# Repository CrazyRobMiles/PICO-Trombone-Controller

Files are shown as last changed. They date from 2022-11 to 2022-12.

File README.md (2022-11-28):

# PICO Trombone controller

Designs and software for a trombone controller.

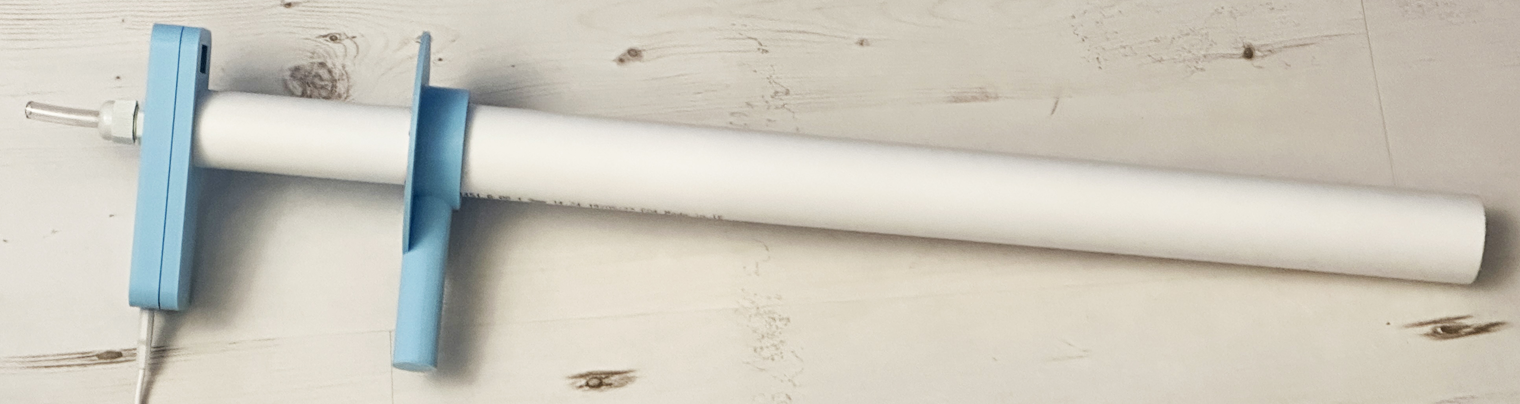
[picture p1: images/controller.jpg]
Trombone controller


## Controlling a mouse with trombone action

The controller can be used to play the game Trombone Champ: https://www.trombonechamp.com/

It replaces the mouse controller. There is a breath controlled version which uses a BMP280 pressure sensor and a button controlled version. 

You will need:

* A Raspberry Pi PICO
* A VL53L4CD time of flight sensor
* A BMP280 temperature and pressure sensor or two pushbuttons that will fit in 12mm diameter holes
* 45 cm of 32mm diameter waste pipe
* 45 cm of 40mm diameter waste pipe
* A micro-USB cable to link the PICO to the host
* Connecting wire. The author used coloured wire wrap (search for "30 AWG wire wrap") which needed a wire wrap tool (search for "wire wrap tool")..
* A case and target. There is a 3D printable set one which fits around the tubing and works well.
* PG9 cable gland for the mouthpiece connector if you are using the BMP280
* 8mm clear vinyl tubing for the mouthpiece. You’ll need a length of around 50mm for each mouthpiece. 
* Screws. You'll need some screws size M2 4mm in length to fix the environmental sensor and PICO to the case (search for "laptop screws").

## Circuit Diagram

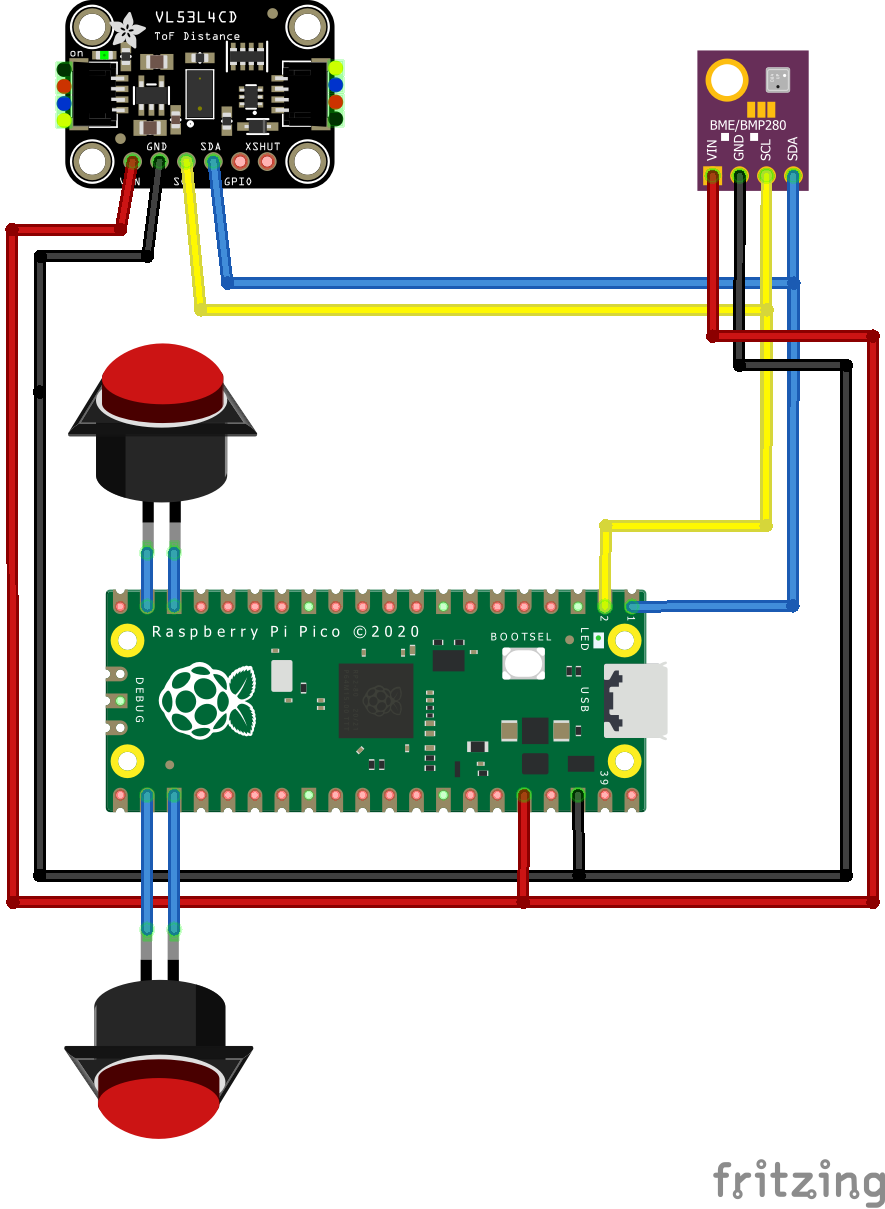
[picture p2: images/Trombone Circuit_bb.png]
Circuit Diagram


The diagram shows the connection for both buttons and air pressur sensor. Ignore the one you're not using. 

## Software Installation

Install Circuit Python 7.0 on your PICO and then copy the lib folder and the code.py file to the PICO. When you power on the PICO it will then run the code. You may need to edit the code.py file to select the input method you are using. 

## Case

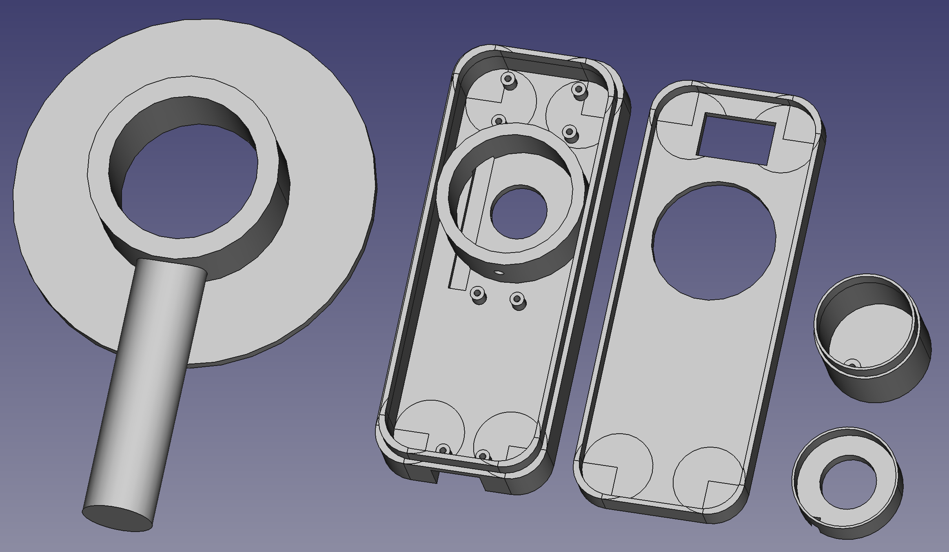
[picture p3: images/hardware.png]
Case Components


The components for the case can be found in the case folder. 

Enjoy playing your trombone
Rob Miles

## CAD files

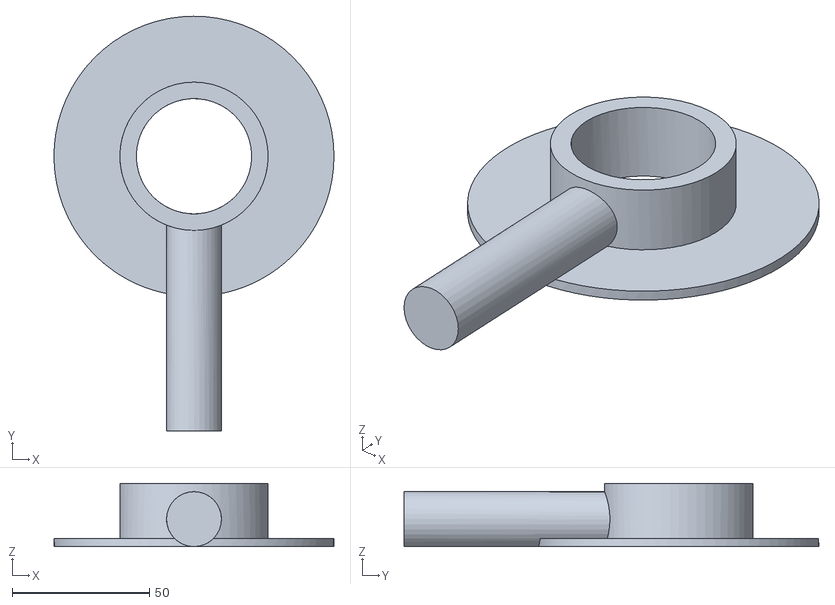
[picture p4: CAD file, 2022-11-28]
case/target.stl
102.0 x 151.0 x 23.0

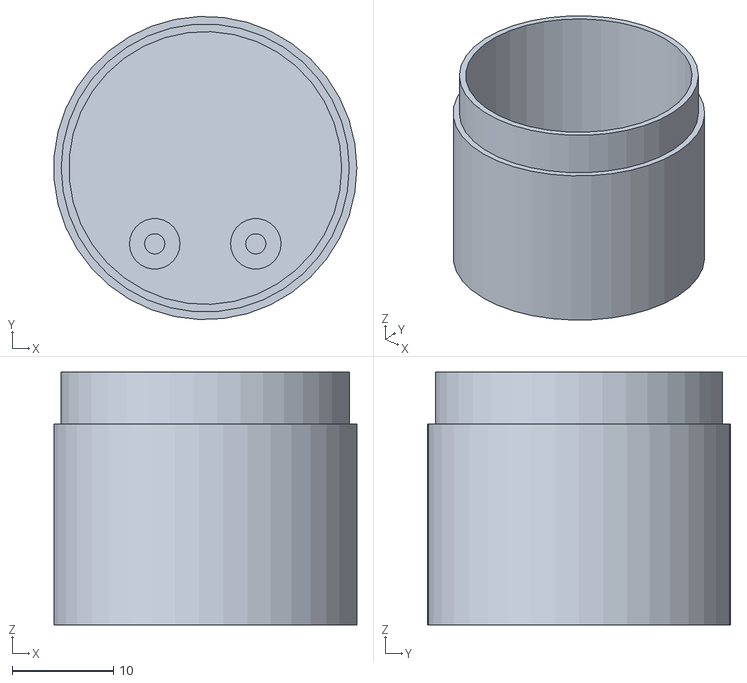
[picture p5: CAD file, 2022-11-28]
case/Pressure Sensor Holder Base.stl
30.0 x 30.0 x 25.0

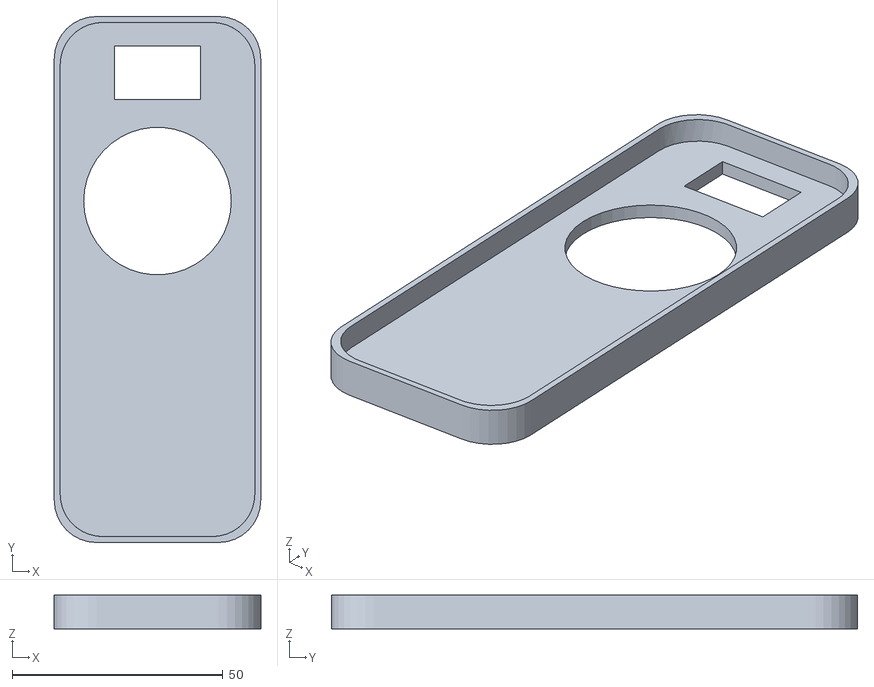
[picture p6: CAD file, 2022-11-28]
case/Top.stl
49.0 x 124.8 x 8.00

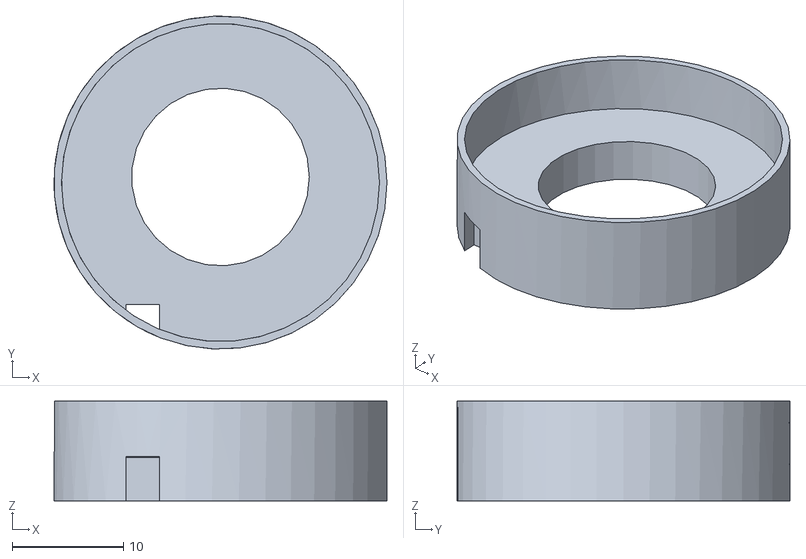
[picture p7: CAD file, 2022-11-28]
case/Pressure Sensor Holder Top.stl
30.0 x 30.0 x 9.00

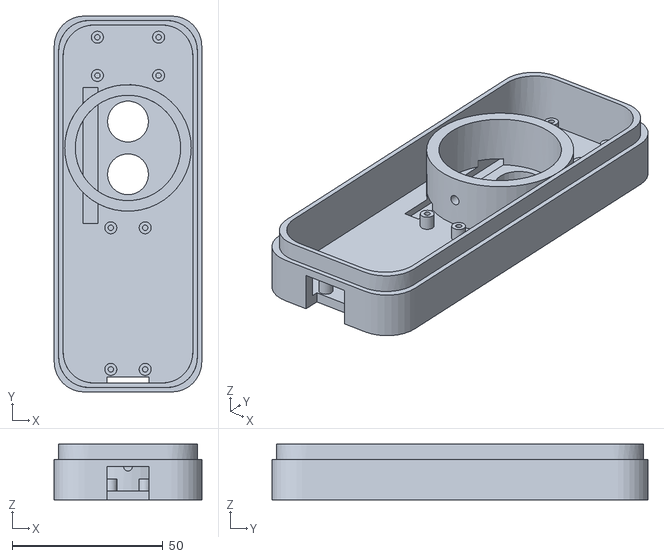
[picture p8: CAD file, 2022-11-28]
case/Two Buttons Base.stl
49.0 x 124.8 x 18.5

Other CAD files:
case/Pressure Sensor Base.stl

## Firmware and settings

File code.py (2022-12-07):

# Trombone controller
#

import board
import busio
import adafruit_vl53l4cd
import adafruit_vl53l0x
import time
import usb_hid
from digitalio import DigitalInOut, Direction, Pull

import adafruit_bmp280
from adafruit_hid.mouse import Mouse

mouse = Mouse(usb_hid.devices)


class Distance():

    def __init__(self):
        self.valuePos = 0
        self.valueTotal = 0
        self.rollingAverageLength = 5
        self.rollingValues = []

        print("Rolling average length:{}".format(self.rollingAverageLength))

        for i in range(0, self.rollingAverageLength):
            self.rollingValues.append(0)

    def distance_moved(self):
        new_pos = self.blockingWaitForValue()
        diff = new_pos - self.current_pos
        self.current_pos = new_pos
        return diff

    def start(self):
        pass

    def blockingWaitForAverage(self, timeout=1):
        distance = self.blockingWaitForValue(timeout=1)

        self.valueTotal = self.valueTotal + distance
        self.valueTotal = self.valueTotal - self.rollingValues[self.valuePos]
        self.rollingValues[self.valuePos] = distance
        self.valuePos = self.valuePos + 1
        if self.valuePos == self.rollingAverageLength:
            self.valuePos = 0
        return int(self.valueTotal/self.rollingAverageLength*10)

    def speed_test(self):
        readingCount = 0
        ot = time.time()
        while True:
            x = self.blockingWaitForValue()
            readingCount = readingCount + 1
            nt = time.time()
            if nt != ot:
                print(readingCount, x)
                readingCount = 0
                ot = nt

    def dump(self):
        while True:
            print(self.blockingWaitForValue())


class DistanceSensor_vl53l0x(Distance):
# https://docs.circuitpython.org/projects/vl53l0x/en/latest/
    def __init__(self, i2c):
        super(DistanceSensor_vl53l0x, self).__init__()
        self.vl53 = adafruit_vl53l0x.VL53L0X(i2c)
        self.vl53.inter_measurement = 10
        print("VL53L0X Starting")

    def start(self):
        super(DistanceSensor_vl53l0x, self).start()
        self.vl53.timing_budget = 10
        self.vl53.start_continuous()
        self.current_pos = self.blockingWaitForValue()

    def blockingWaitForValue(self, timeout=1):
        end = time.monotonic() + 1
        while not self.vl53.data_ready:
            if time.monotonic() > end:
                break
        if time.monotonic() > end:
            return -1
        else:
            return self.vl53.range


class DistanceSensor_vl53l4cd(Distance):
# https://docs.circuitpython.org/projects/vl53l4cd/en/latest/api.html#adafruit_vl53l4cd.VL53L4CD
    def __init__(self, i2c):
        super(DistanceSensor_vl53l4cd, self).__init__()
        self.vl53 = adafruit_vl53l4cd.VL53L4CD(i2c)
        print("VL53L4CD Starting")

    def start(self):
        super(DistanceSensor_vl53l4cd, self).start()
        self.vl53.timing_budget = 10
        self.vl53.start_ranging()
        self.current_pos = self.blockingWaitForValue()

    def blockingWaitForValue(self, timeout=1):
        end = time.monotonic() + 1
        while not self.vl53.data_ready:
            if time.monotonic() > end:
                break
        if time.monotonic() > end:
            return -1
        else:
            self.vl53.clear_interrupt()
            return self.vl53.distance * 10


class PlaySensor():

    def __init__(self):
        pass

    def speed_test(self):
        readingCount = 0
        ot = time.time()
        while True:
            x = self.play_pressed()
            readingCount = readingCount + 1
            nt = time.time()
            if nt != ot:
                print(readingCount, x)
                readingCount = 0
                ot = nt

class DummyPlaySensor(PlaySensor):
    def __init__(self):
        super(DummyPlaySensor, self).__init__()

    def play_pressed(self):
        return False


class PressureSensor_BMP280(PlaySensor):

    def __init__(self, i2c):
        super(PressureSensor_BMP280, self).__init__()
        self.bmp280 = adafruit_bmp280.Adafruit_BMP280_I2C(i2c, address=0x76)
        self.pressure_detect = 5
        self.base_pressure = self.bmp280.pressure

    def play_pressed(self):
        pressure_change = self.bmp280.pressure - self.base_pressure
        return pressure_change > self.pressure_detect


class ButtonPlaySensor(PlaySensor):

    def __init__(self, pin):
        super(ButtonPlaySensor, self).__init__()
        self.red_button = DigitalInOut(pin)
        self.red_button.switch_to_input(pull=Pull.UP)

    def play_pressed(self):
        return self.red_button.value == False


i2c_sda = board.GP0
i2c_scl = board.GP1
i2c = busio.I2C(i2c_scl, i2c_sda)

# Select the distance sensor and play sensors that you are 
# using in your configuration by commenting out the 
# ones you're not using

distance = DistanceSensor_vl53l0x(i2c)
#distance = DistanceSensor_vl53l4cd(i2c)
distance.start()
# distance.dump()
#play = DummyPlaySensor()
play = ButtonPlaySensor(board.GP17)
#play = PressureSensor_BMP280(i2c)

mouse_down = False
readingCount = 0
ot = time.time()
old_dist = distance.blockingWaitForAverage()
# Adjust this value depending on taste for the amount of mouse movement when the controller is moved
speed = 0.4

while True:
    dist = distance.blockingWaitForAverage()
    if dist < 30:
        pass
    else:
        change = old_dist-dist
        mouse_dist = int(change*speed)
        if mouse_dist != 0:
            mouse.move(y=mouse_dist)
        if play.play_pressed():
            if mouse_down == False:
                mouse.press(Mouse.LEFT_BUTTON)
                print("toot")
                mouse_down = True
        else:
            if mouse_down == True:
                mouse.release(Mouse.LEFT_BUTTON)
                print("untoot")
                mouse_down = False
    old_dist = dist
    # This displays the update rate per second
    readingCount = readingCount + 1
    nt = time.time()
    if nt != ot:
        print(readingCount, dist)
        readingCount = 0
        ot = nt

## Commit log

2022-11-28 First release
    [Pressure Sensor Base.stl, Pressure Sensor Holder Base.stl, Pressure Sensor Holder Top.stl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]
2022-11-28 Reset default sensors
2022-12-07 Fixed pin setting in ButtonPlaySensor constructor
    [code.py]
